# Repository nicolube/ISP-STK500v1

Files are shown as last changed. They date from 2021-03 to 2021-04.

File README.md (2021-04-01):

# ISP an Hand einer STK500v1
Diese ISP ist im grunde einer [STK500v1](http://ww1.microchip.com/downloads/en/Appnotes/doc2525.pdf) auch bekannt als [Arduino as ISP](https://www.arduino.cc/en/Tutorial/BuiltInExamples/ArduinoISP) mit der erweitern Schnittstelle für das [ATMega32 Board](/ATMega32%20Board/ATMega32%20Board.pdf) der IHK.
## Inhaltsverzeichnis
- [ISP an Hand einer STK500v1](#isp-an-hand-einer-stk500v1)
  - [Inhaltsverzeichnis](#inhaltsverzeichnis)
- [Bedienung](#bedienung)
  - [Jumper](#jumper)
  - [Arduino IDE](#arduino-ide)
  - [PlatformIO](#platformio)
  - [Schnittstellen Beschreibung](#schnittstellen-beschreibung)
- [Bauteile die vernachlässicht werden können](#bauteile-die-vernachlässicht-werden-können)
- [Programmieren der ISP](#programmieren-der-isp)
  - [Flashen der Firmware](#flashen-der-firmware)
- [Bestückungsplan](#bestückungsplan)
- [Schaltplan](#schaltplan)

# Bedienung

Das Board ist wie am Anfang genant eine STK500v1 und verhält sich auch so. Es registriert sich auf der Seite des PC als Serielle Schnittstelle.

Bevor Sie jedoch ihr zu Programirendes Board anschießen muss geprüft werden ob das zu programmirende Board eine eigene Spannungsversorgung hat und ob diese auf die AVR ISP Schnittstelle geführt wird. Sollte dies der Fall sein so entfernen Sie bitte JP2.

## Jumper

- ### JP1 Programmier Modus 
  
  JP1 muss im normalfall immer auf der Stellung (2,3) sein.
In der Stellung (1,2) ist die ISP im Selbst Programmiermodus und kann durch eine andere ISP geflasht werden. 

- ### JP2 Spannung über ISP

  Wenn die zu programmirende Board eine Stromaufnahme unter 100mA besitzt kann JP2 dazu genutzt werden die Board mit Spannung zu versorgen. **Dies darf nur im Spannungfreien zustand des Bords genutzt werden**

## Arduino IDE

Wählen Sie unter Tools den Port Ihrer STK500v1 und den Programmer *Arduino as ISP*.
Jetzt kann wie gewohnt ihr Programm hochgeladen werden.

Für genauere Informationen Klicken Sie [hier](https://www.arduino.cc/en/Tutorial/BuiltInExamples/ArduinoISP#program-the-bootloader) 

## PlatformIO

Bitte nutzen Sie für PlatformIO Projekt unser [Beispiel Projekt](/ISP/Beispiel).
Hier bei ist zu Beachten das in der [platform.ini](/ISP/Beispiel/platformio.ini) der *upload_port* angepasst werden muss.

## Schnittstellen Beschreibung

- SV1 und SV2 sind eine 6-, 10-Pin [AVR ISP Schittstelle](https://telecnatron.com/reference/pinouts/avr-isp/index.html).
- X1 ist ebenfalls eine ISP jedoch adoptiert auf den Parallelen Port des [ATMega32 Board](/ATMega32%20Board/ATMega32%20Board.pdf)
- X2 [USB Type B](https://static.giga.de/wp-content/uploads/2015/06/USB-2.0-A-B-Pins.png) zur Kommunikation mit dem PC.

# Bauteile die vernachlässicht werden können
Die Leiterplatte hat verschiedene Zusatzkomponenten die für die Funktion nicht zwingen benötigt werden, jedoch zusätzliche sicherheiten gewähren.

- Entstörkondensatoren USB (C8, C9)
- ESD-Schutz Diodennetzwerk (U1)
- FT232: Reset Pulldown (R5)
- FT232: 3,3V Entstörer (C7)

# Programmieren der ISP

Zum Programiren der ISP muss JP1 (1,2) und JP2 gesetzt werden.
Nun kann mittels einer anderen ISP die [Firmware](/ISP/Firmware/) geflasht werden.
Zudem muss SV1 oder SV2 auf ein Programmiergerät gebückt werden, dies kann z.b. eine USBASP oder eine andere ISP sein.

**Prüfen Sie die Stellung der Jumper!**

## Flashen der Firmware
1. Begeben Sie sich in den Verzeichnis des Projektes.
2. Prüfen Sie in der [platform.ini](/ISP/Firmware/platformio.ini) ob Sie den richtigen *upload_port* gewählt haben.
3. Öffenen Sie nun ein Terminal / CMD die [PlatformIO CLI](https://platformio.org/install/cli) installiert hat.
4. Setzen Sie die Fuses des Mikrocontrollers mit ```pio run --target fuses```.
5. Laden Sie nun die Firmware mit ```pio run --target upload``` hoch.

>  Bitte beachten Sie das der Jumper JP1 zur normalen nutzung wieder auf JP1 (2,3) gesetzt werden muss.

# Bestückungsplan
**Siehe [Stückliste](/ISP/Eagle/Stückliste.txt) für Bauteilinformation.**

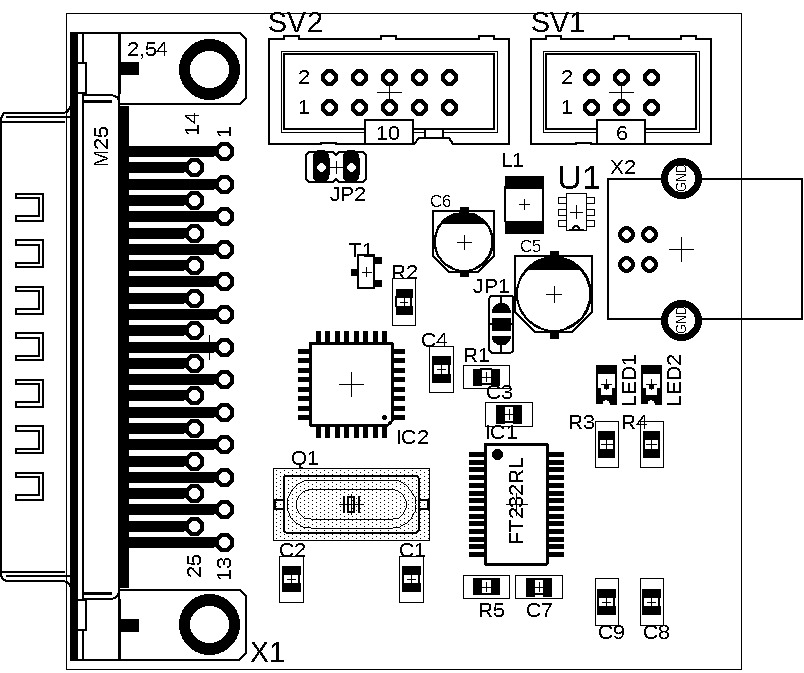
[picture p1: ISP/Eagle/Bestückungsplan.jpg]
Bestückungsplan


# Schaltplan
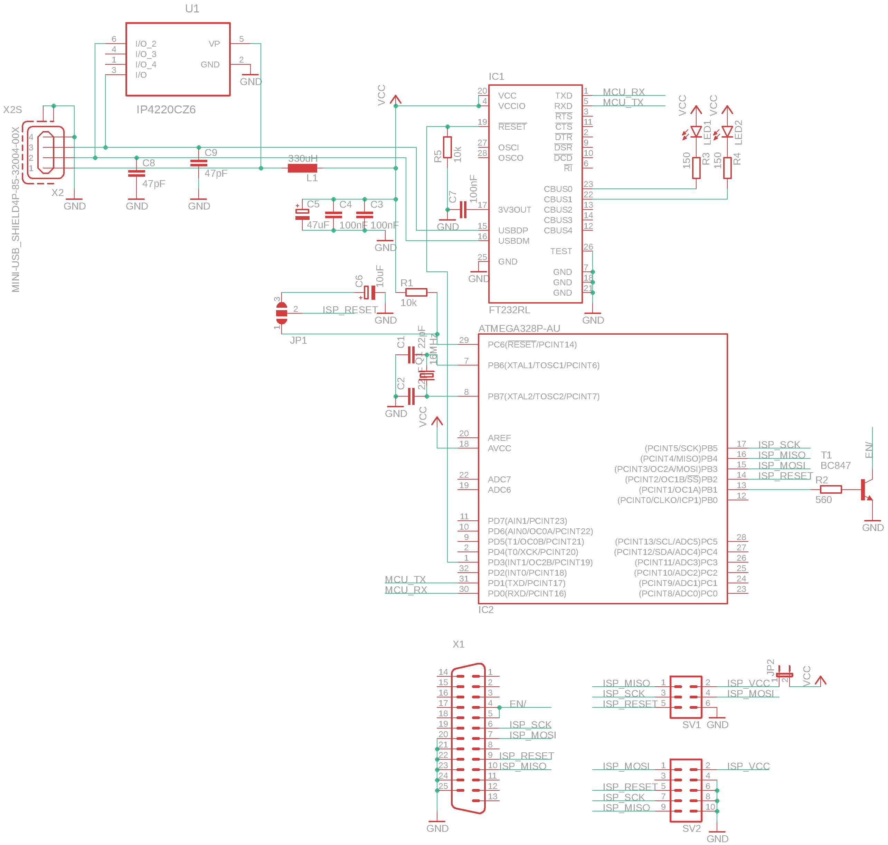
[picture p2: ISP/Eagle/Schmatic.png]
Schaltplan


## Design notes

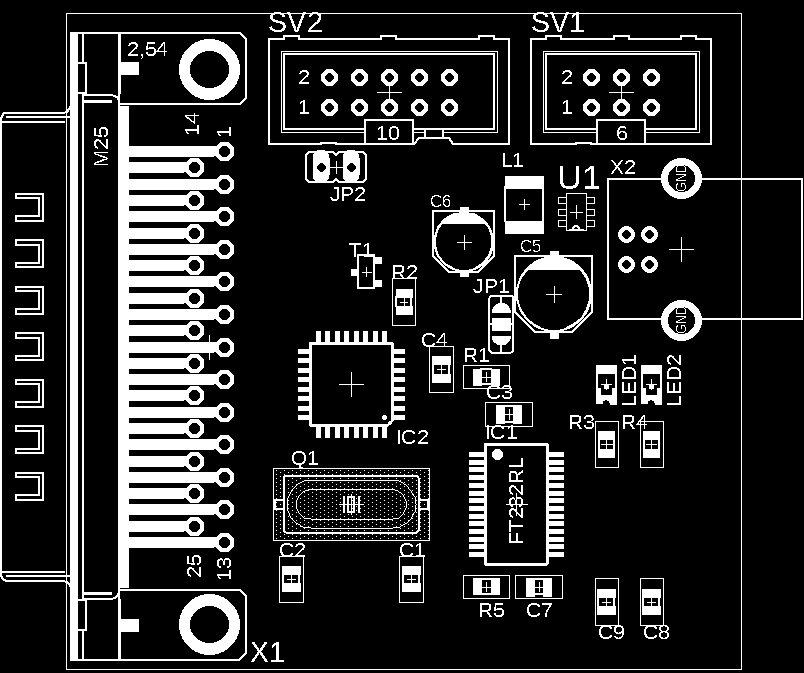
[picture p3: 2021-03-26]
ISP/Eagle/Bestückungsplan.png

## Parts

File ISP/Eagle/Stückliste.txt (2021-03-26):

Partlist

Exported from ISP.brd at 26.03.21 08:14

EAGLE Version 9.5.1 Copyright (c) 1988-2019 Autodesk, Inc.

Assembly variant: 

Part     Value                          Package          Library               Position (mil)        Orientation

C1       22pF                           C0805            resistor              (1150 300)            R90
C2       22pF                           C0805            resistor              (750 300)             R90
C3       100nF                          C0805            resistor              (1475 850)            R0
C4       100nF                          C0805            resistor              (1250 1000)           R90
C5       47uF                           PANASONIC_D      resistor              (1625 1250)           R270
C6       10uF                           PANASONIC_C      resistor              (1325 1425)           R270
C7       100nF                          C0805            resistor              (1575 275)            R180
C8       47pF                           C0805            resistor              (1950 225)            R270
C9       47pF                           C0805            resistor              (1800 225)            R270
IC1      FT232RL                        SSOP28           ftdichip              (1500 550)            R270
IC2      ATMEGA328P-AU                  QFP32_7X7_0.80   atmel                 (950 950)             R180
JP1                                     SJ_2             jumper                (1450 1150)           R90
JP2                                     JP1              jumper                (900 1675)            R90
L1       330uH                          L1812            resistor              (1525 1550)           R270
LED1                                    CHIPLED_1206     led                   (1800 950)            R180
LED2                                    CHIPLED_1206     led                   (1950 950)            R180
Q1       16MHz                          HC49UP           crystal               (950 550)             R0
R1       10k                            R0805            resistor              (1400 975)            R0
R2       560                            R0805            resistor              (1125 1225)           R90
R3       150                            R0805            resistor              (1800 750)            R270
R4       150                            R0805            resistor              (1950 750)            R270
R5       10k                            R0805            resistor              (1400 275)            R0
SV1                                     ML6              con-harting-ml        (1850 1925)           R0
SV2                                     ML10             con-ml                (1075 1925)           R0
T1       BC847                          SOT23            transistor            (1000 1325)           R90
U1       IP4220CZ6                      SOT95P275X110-6N IP4220CZ6             (1700 1525)           R180
X1                                      M25HP            con-subd              (475 1075)            R270
X2       MINI-USB_SHIELD4P-85-32004-00X 85-32004-00X     con-cypressindustries (2050 1400)           R180

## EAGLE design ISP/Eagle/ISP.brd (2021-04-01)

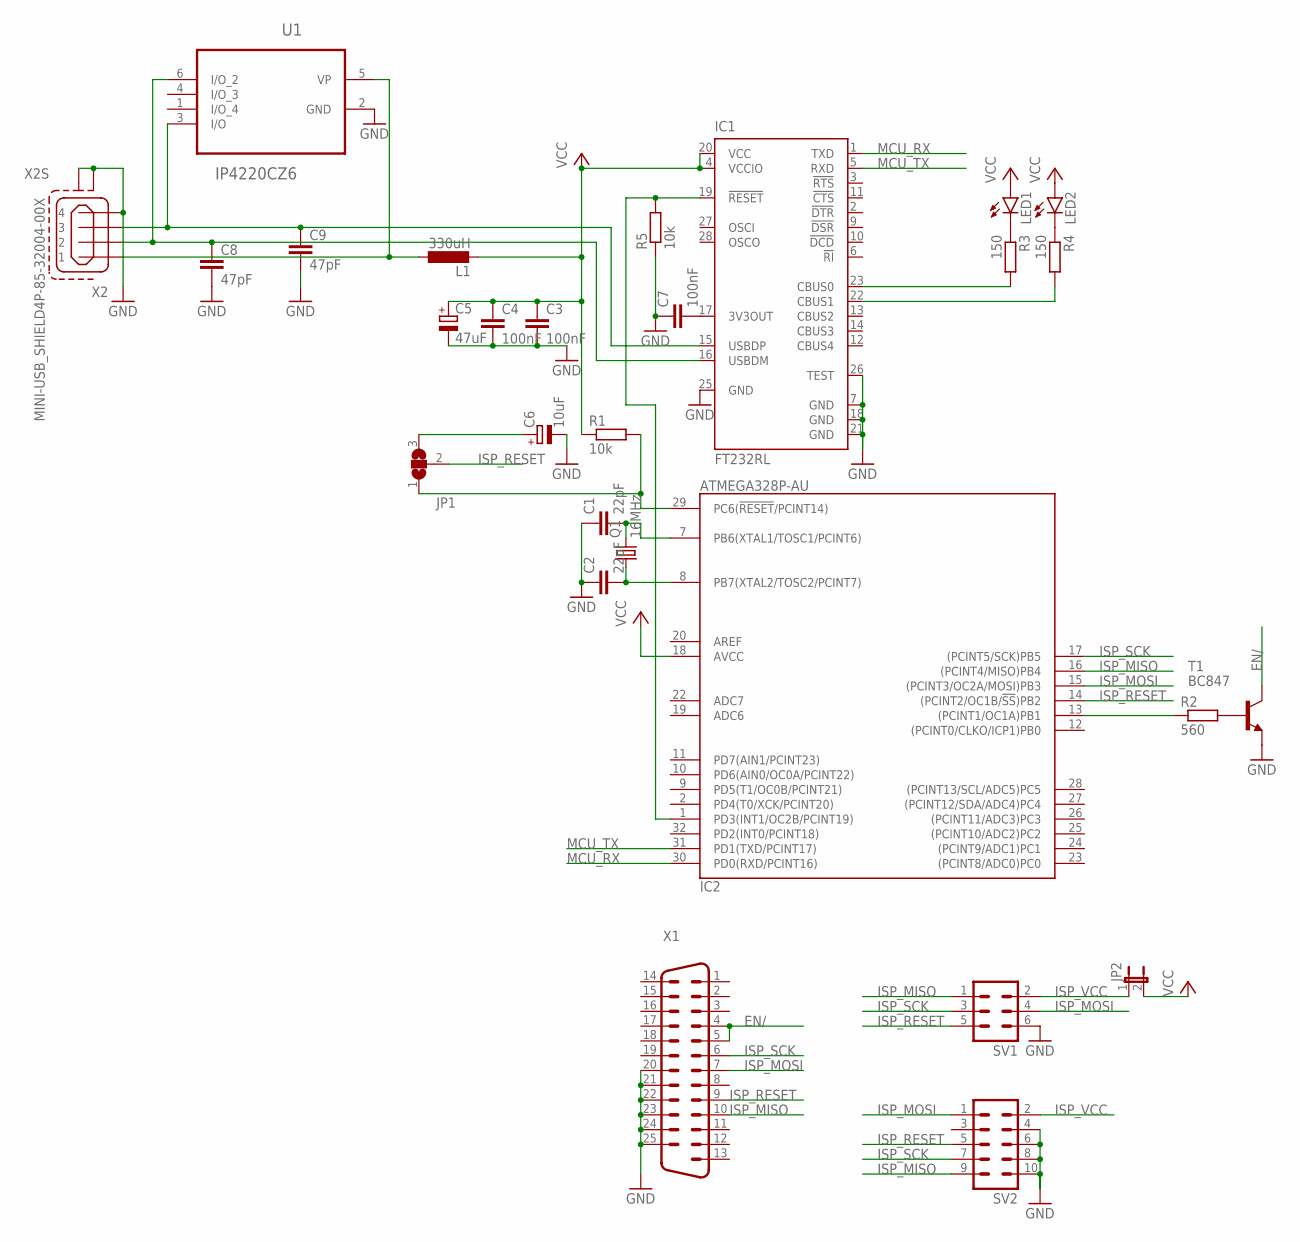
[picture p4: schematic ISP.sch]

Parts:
C1, C2: 22pF; C0805
C3, C4, C7: 100nF; C0805
C5: 47uF; PANASONIC_D
C6: 10uF; PANASONIC_C
C8, C9: 47pF; C0805
IC1: FT232RL; SSOP28
IC2: ATMEGA328P-AU; QFP32_7X7_0.80
JP1: SJ2W; SJ_2
JP2: JP1E; JP1
L1: 330uH; L1812
LED1, LED2: LEDCHIPLED_1206; CHIPLED_1206
Q1: 16MHz; HC49UP
R1, R5: 10k; R0805
R2: 560; R0805
R3, R4: 150; R0805
SV1: ML6
SV2: ML10
T1: BC847; SOT23
U1: IP4220CZ6; SOT95P275X110-6N
X1: M25HP
X2: MINI-USB_SHIELD4P-85-32004-00X; 85-32004-00X

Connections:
EN/: T1.3 (C), X1.4, X1.5
GND: C1.1, C2.1, C3.2, C4.2, C5.-, C6.-, C7.1, C8.2, C9.2, IC1.7 (GND), IC1.18 (GND), IC1.21 (GND), IC1.25 (GND), IC1.26 (TEST), IC2.3 (GND), IC2.5 (GND), IC2.21 (GND), R5.1, SV1.6, SV2.4, SV2.6, SV2.8, SV2.10, T1.2 (E), U1.2 (GND), X1.20, X1.21, X1.22, X1.23, X1.24, X1.25, X2.4, X2.M1 (S1), X2.M2 (S2)
ISP_MISO: IC2.16 ((PCINT4/MISO)PB4), SV1.1, SV2.9, X1.10
ISP_MOSI: IC2.15 ((PCINT3/OC2A/MOSI)PB3), SV1.4, SV2.1, X1.7
ISP_RESET: IC2.14 ((PCINT2/OC1B/!SS!)PB2), JP1.2, SV1.5, SV2.5, X1.9
ISP_SCK: IC2.17 ((PCINT5/SCK)PB5), SV1.3, SV2.7, X1.6
ISP_VCC: JP2.1, SV1.2, SV2.2
MCU_RX: IC1.1 (TXD), IC2.30 (PD0(RXD/PCINT16))
MCU_TX: IC1.5 (RXD), IC2.31 (PD1(TXD/PCINT17))
unnamed: IC2.29 (PC6(!RESET!/PCINT14)), JP1.1, R1.2
unnamed: C6.+, JP1.3
unnamed: C1.2, IC2.7 (PB6(XTAL1/TOSC1/PCINT6)), Q1.2
unnamed: C9.1, IC1.15 (USBDP), U1.3 (I/O), X2.3
unnamed: IC2.13 ((PCINT1/OC1A)PB1), R2.1
unnamed: R2.2, T1.1 (B)
unnamed: C8.1, IC1.16 (USBDM), U1.6 (I/O_2), X2.2
unnamed: C7.2, IC1.17 (3V3OUT)
unnamed: C2.2, IC2.8 (PB7(XTAL2/TOSC2/PCINT7)), Q1.1
unnamed: LED2.C, R4.1
unnamed: LED1.C, R3.1
unnamed: IC1.23 (CBUS0), R3.2
unnamed: IC1.22 (CBUS1), R4.2
unnamed: L1.1, U1.5 (VP), X2.1
unnamed: IC1.19 (!RESET), IC2.1 (PD3(INT1/OC2B/PCINT19)), R5.2
VCC: C3.1, C4.1, C5.+, IC1.4 (VCCIO), IC1.20 (VCC), IC2.4 (VCC), IC2.6 (VCC), IC2.18 (AVCC), JP2.2, L1.2, LED1.A, LED2.A, R1.1

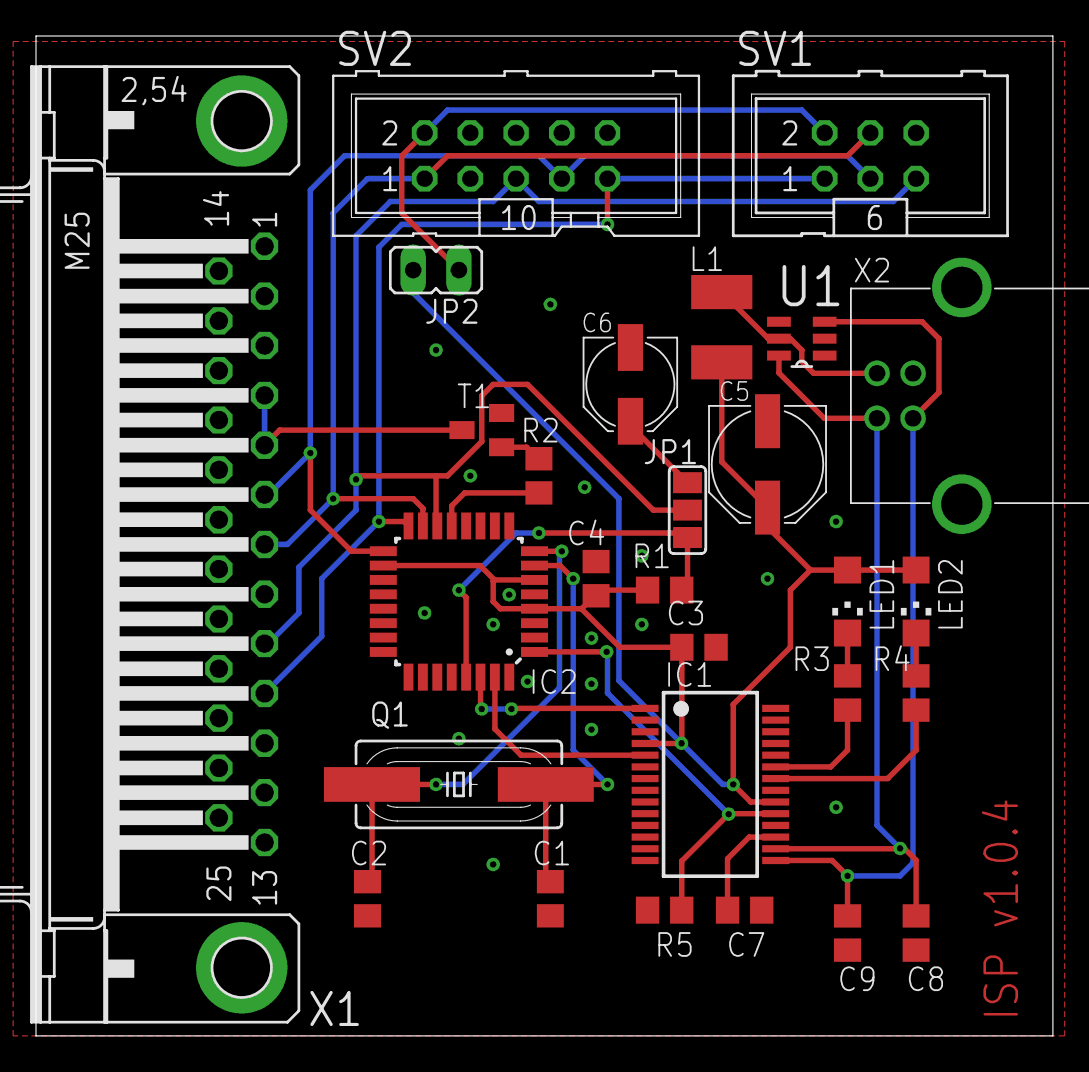
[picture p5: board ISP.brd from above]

Board: 2 copper layers, 56.5 x 55.5 mm, 28 parts (0 on the bottom side), 25 nets.

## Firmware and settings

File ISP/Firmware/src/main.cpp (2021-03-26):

#define PROG_EN 9
#define PROG_INV false
#define FT232_EN 3

unsigned long lSend = 0;

// ArduinoISP
// Copyright (c) 2008-2011 Randall Bohn
// If you require a license, see
// http://www.opensource.org/licenses/bsd-license.php
//
// This sketch turns the Arduino into a AVRISP using the following Arduino pins:
//
// Pin 10 is used to reset the target microcontroller.
//
// By default, the hardware SPI pins MISO, MOSI and SCK are used to communicate
// with the target. On all Arduinos, these pins can be found
// on the ICSP/SPI header:
//
//               MISO °. . 5V (!) Avoid this pin on Due, Zero...
//               SCK   . . MOSI
//                     . . GND
//
// On some Arduinos (Uno,...), pins MOSI, MISO and SCK are the same pins as
// digital pin 11, 12 and 13, respectively. That is why many tutorials instruct
// you to hook up the target to these pins. If you find this wiring more
// practical, have a define USE_OLD_STYLE_WIRING. This will work even when not
// using an Uno. (On an Uno this is not needed).
//
// Alternatively you can use any other digital pin by configuring
// software ('BitBanged') SPI and having appropriate defines for PIN_MOSI,
// PIN_MISO and PIN_SCK.
//
// IMPORTANT: When using an Arduino that is not 5V tolerant (Due, Zero, ...) as
// the programmer, make sure to not expose any of the programmer's pins to 5V.
// A simple way to accomplish this is to power the complete system (programmer
// and target) at 3V3.
//
// Put an LED (with resistor) on the following pins:
// 9: Heartbeat   - shows the programmer is running
// 8: Error       - Lights up if something goes wrong (use red if that makes sense)
// 7: Programming - In communication with the slave
//

#include "Arduino.h"
#undef SERIAL


#define PROG_FLICKER true

// Configure SPI clock (in Hz).
// E.g. for an ATtiny @ 128 kHz: the datasheet states that both the high and low
// SPI clock pulse must be > 2 CPU cycles, so take 3 cycles i.e. divide target
// f_cpu by 6:
//     #define SPI_CLOCK            (128000/6)
//
// A clock slow enough for an ATtiny85 @ 1 MHz, is a reasonable default:

#define SPI_CLOCK 		(1000000/6)


// Select hardware or software SPI, depending on SPI clock.
// Currently only for AVR, for other architectures (Due, Zero,...), hardware SPI
// is probably too fast anyway.

#if defined(ARDUINO_ARCH_AVR)

#if SPI_CLOCK > (F_CPU / 128)
#define USE_HARDWARE_SPI
#endif

#endif

// Configure which pins to use:

// The standard pin configuration.
#ifndef ARDUINO_HOODLOADER2

#define RESET     10 // Use pin 10 to reset the target rather than SS
#define LED_HB    6
#define LED_ERR   8
#define LED_PMODE 7

// Uncomment following line to use the old Uno style wiring
// (using pin 11, 12 and 13 instead of the SPI header) on Leonardo, Due...

// #define USE_OLD_STYLE_WIRING

#ifdef USE_OLD_STYLE_WIRING

#define PIN_MOSI	11
#define PIN_MISO	12
#define PIN_SCK		13

#endif

// HOODLOADER2 means running sketches on the ATmega16U2 serial converter chips
// on Uno or Mega boards. We must use pins that are broken out:
#else

#define RESET     	4
#define LED_HB    	7
#define LED_ERR   	6
#define LED_PMODE 	5

#endif

// By default, use hardware SPI pins:
#ifndef PIN_MOSI
#define PIN_MOSI 	MOSI
#endif

#ifndef PIN_MISO
#define PIN_MISO 	MISO
#endif

#ifndef PIN_SCK
#define PIN_SCK 	SCK
#endif

// Force bitbanged SPI if not using the hardware SPI pins:
#if (PIN_MISO != MISO) ||  (PIN_MOSI != MOSI) || (PIN_SCK != SCK)
#undef USE_HARDWARE_SPI
#endif


// Configure the serial port to use.
//
// Prefer the USB virtual serial port (aka. native USB port), if the Arduino has one:
//   - it does not autoreset (except for the magic baud rate of 1200).
//   - it is more reliable because of USB handshaking.
//
// Leonardo and similar have an USB virtual serial port: 'Serial'.
// Due and Zero have an USB virtual serial port: 'SerialUSB'.
//
// On the Due and Zero, 'Serial' can be used too, provided you disable autoreset.
// To use 'Serial': #define SERIAL Serial

#ifdef SERIAL_PORT_USBVIRTUAL
#define SERIAL SERIAL_PORT_USBVIRTUAL
#else
#define SERIAL Serial
#endif


// Configure the baud rate:

#define BAUDRATE	19200
// #define BAUDRATE	115200
// #define BAUDRATE	1000000


#define HWVER 2
#define SWMAJ 1
#define SWMIN 18

// STK Definitions
#define STK_OK      0x10
#define STK_FAILED  0x11
#define STK_UNKNOWN 0x12
#define STK_INSYNC  0x14
#define STK_NOSYNC  0x15
#define CRC_EOP     0x20 //ok it is a space...

void pulse(int pin, int times);

#ifdef USE_HARDWARE_SPI
#include "SPI.h"
#else

#define SPI_MODE0 0x00

class SPISettings {
  public:
    // clock is in Hz
    SPISettings(uint32_t clock, uint8_t bitOrder, uint8_t dataMode) : clock(clock) {
      (void) bitOrder;
      (void) dataMode;
    };

  private:
    uint32_t clock;

    friend class BitBangedSPI;
};

class BitBangedSPI {
  public:
    void begin() {
      digitalWrite(PIN_SCK, LOW);
      digitalWrite(PIN_MOSI, LOW);
      pinMode(PIN_SCK, OUTPUT);
      pinMode(PIN_MOSI, OUTPUT);
      pinMode(PIN_MISO, INPUT);
    }

    void beginTransaction(SPISettings settings) {
      pulseWidth = (500000 + settings.clock - 1) / settings.clock;
      if (pulseWidth == 0)
        pulseWidth = 1;
    }

    void end() {}

    uint8_t transfer (uint8_t b) {
      for (unsigned int i = 0; i < 8; ++i) {
        digitalWrite(PIN_MOSI, (b & 0x80) ? HIGH : LOW);
        digitalWrite(PIN_SCK, HIGH);
        delayMicroseconds(pulseWidth);
        b = (b << 1) | digitalRead(PIN_MISO);
        digitalWrite(PIN_SCK, LOW); // slow pulse
        delayMicroseconds(pulseWidth);
      }
      return b;
    }

  private:
    unsigned long pulseWidth; // in microseconds
};

static BitBangedSPI SPI;

#endif



int error = 0;
int pmode = 0;
// address for reading and writing, set by 'U' command
unsigned int here;
uint8_t buff[256]; // global block storage

#define beget16(addr) (*addr * 256 + *(addr+1) )
typedef struct param {
  uint8_t devicecode;
  uint8_t revision;
  uint8_t progtype;
  uint8_t parmode;
  uint8_t polling;
  uint8_t selftimed;
  uint8_t lockbytes;
  uint8_t fusebytes;
  uint8_t flashpoll;
  uint16_t eeprompoll;
  uint16_t pagesize;
  uint16_t eepromsize;
  uint32_t flashsize;
}
parameter;

parameter param;

// this provides a heartbeat on pin 9, so you can tell the software is running.
uint8_t hbval = 128;
int8_t hbdelta = 8;
void heartbeat() {
  static unsigned long last_time = 0;
  unsigned long now = millis();
  if ((now - last_time) < 40)
    return;
  last_time = now;
  if (hbval > 192) hbdelta = -hbdelta;
  if (hbval < 32) hbdelta = -hbdelta;
  hbval += hbdelta;
  analogWrite(LED_HB, hbval);
}

static bool rst_active_high;

void reset_target(bool reset) {
  digitalWrite(RESET, ((reset && rst_active_high) || (!reset && !rst_active_high)) ? HIGH : LOW);
}

uint8_t getch() {
  while (!SERIAL.available()) {
    if (millis() > lSend)
      digitalWrite(PROG_EN, PROG_INV);
  }
  lSend = millis() + 100;
  return SERIAL.read();
}
void fill(int n) {
  for (int x = 0; x < n; x++) {
    buff[x] = getch();
  }
}

#define PTIME 30
void pulse(int pin, int times) {
  do {
    digitalWrite(pin, HIGH);
    delay(PTIME);
    digitalWrite(pin, LOW);
    delay(PTIME);
  } while (times--);
}

void prog_lamp(int state) {
  if (PROG_FLICKER) {
    digitalWrite(LED_PMODE, state);
  }
}

uint8_t spi_transaction(uint8_t a, uint8_t b, uint8_t c, uint8_t d) {
  SPI.transfer(a);
  SPI.transfer(b);
  SPI.transfer(c);
  return SPI.transfer(d);
}

void empty_reply() {
  if (CRC_EOP == getch()) {
    SERIAL.print((char)STK_INSYNC);
    SERIAL.print((char)STK_OK);
  } else {
    error++;
    SERIAL.print((char)STK_NOSYNC);
  }
}

void breply(uint8_t b) {
  if (CRC_EOP == getch()) {
    SERIAL.print((char)STK_INSYNC);
    SERIAL.print((char)b);
    SERIAL.print((char)STK_OK);
  } else {
    error++;
    SERIAL.print((char)STK_NOSYNC);
  }
}

void get_version(uint8_t c) {
  switch (c) {
    case 0x80:
      breply(HWVER);
      break;
    case 0x81:
      breply(SWMAJ);
      break;
    case 0x82:
      breply(SWMIN);
      break;
    case 0x93:
      breply('S'); // serial programmer
      break;
    default:
      breply(0);
  }
}

void set_parameters() {
  // call this after reading parameter packet into buff[]
  param.devicecode = buff[0];
  param.revision   = buff[1];
  param.progtype   = buff[2];
  param.parmode    = buff[3];
  param.polling    = buff[4];
  param.selftimed  = buff[5];
  param.lockbytes  = buff[6];
  param.fusebytes  = buff[7];
  param.flashpoll  = buff[8];
  // ignore buff[9] (= buff[8])
  // following are 16 bits (big endian)
  param.eeprompoll = beget16(&buff[10]);
  param.pagesize   = beget16(&buff[12]);
  param.eepromsize = beget16(&buff[14]);

  // 32 bits flashsize (big endian)
  param.flashsize = buff[16] * 0x01000000
                    + buff[17] * 0x00010000
                    + buff[18] * 0x00000100
                    + buff[19];

  // AVR devices have active low reset, AT89Sx are active high
  rst_active_high = (param.devicecode >= 0xe0);
}

void start_pmode() {
  // Reset target before driving PIN_SCK or PIN_MOSI

  // SPI.begin() will configure SS as output, so SPI master mode is selected.
  // We have defined RESET as pin 10, which for many Arduinos is not the SS pin.
  // So we have to configure RESET as output here,
  // (reset_target() first sets the correct level)
  reset_target(true);
  pinMode(RESET, OUTPUT);
  SPI.begin();
  SPI.beginTransaction(SPISettings(SPI_CLOCK, MSBFIRST, SPI_MODE0));

  // See AVR datasheets, chapter "SERIAL_PRG Programming Algorithm":

  // Pulse RESET after PIN_SCK is low:
  digitalWrite(PIN_SCK, LOW);
  delay(20); // discharge PIN_SCK, value arbitrarily chosen
  reset_target(false);
  // Pulse must be minimum 2 target CPU clock cycles so 100 usec is ok for CPU
  // speeds above 20 KHz
  delayMicroseconds(100);
  reset_target(true);

  // Send the enable programming command:
  delay(50); // datasheet: must be > 20 msec
  spi_transaction(0xAC, 0x53, 0x00, 0x00);
  pmode = 1;
}

void end_pmode() {
  SPI.end();
  // We're about to take the target out of reset so configure SPI pins as input
  pinMode(PIN_MOSI, INPUT);
  pinMode(PIN_SCK, INPUT);
  reset_target(false);
  pinMode(RESET, INPUT);
  pmode = 0;
}

void universal() {
  uint8_t ch;

  fill(4);
  ch = spi_transaction(buff[0], buff[1], buff[2], buff[3]);
  breply(ch);
}

void flash(uint8_t hilo, unsigned int addr, uint8_t data) {
  spi_transaction(0x40 + 8 * hilo,
                  addr >> 8 & 0xFF,
                  addr & 0xFF,
                  data);
}
void commit(unsigned int addr) {
  if (PROG_FLICKER) {
    prog_lamp(LOW);
  }
  spi_transaction(0x4C, (addr >> 8) & 0xFF, addr & 0xFF, 0);
  if (PROG_FLICKER) {
    delay(PTIME);
    prog_lamp(HIGH);
  }
}

unsigned int current_page() {
  if (param.pagesize == 32) {
    return here & 0xFFFFFFF0;
  }
  if (param.pagesize == 64) {
    return here & 0xFFFFFFE0;
  }
  if (param.pagesize == 128) {
    return here & 0xFFFFFFC0;
  }
  if (param.pagesize == 256) {
    return here & 0xFFFFFF80;
  }
  return here;
}

// write (length) bytes, (start) is a byte address
uint8_t write_eeprom_chunk(unsigned int start, unsigned int length) {
  // this writes byte-by-byte, page writing may be faster (4 bytes at a time)
  fill(length);
  prog_lamp(LOW);
  for (unsigned int x = 0; x < length; x++) {
    unsigned int addr = start + x;
    spi_transaction(0xC0, (addr >> 8) & 0xFF, addr & 0xFF, buff[x]);
    delay(45);
  }
  prog_lamp(HIGH);
  return STK_OK;
}


#define EECHUNK (32)
uint8_t write_eeprom(unsigned int length) {
  // here is a word address, get the byte address
  unsigned int start = here * 2;
  unsigned int remaining = length;
  if (length > param.eepromsize) {
    error++;
    return STK_FAILED;
  }
  while (remaining > EECHUNK) {
    write_eeprom_chunk(start, EECHUNK);
    start += EECHUNK;
    remaining -= EECHUNK;
  }
  write_eeprom_chunk(start, remaining);
  return STK_OK;
}

uint8_t write_flash_pages(int length) {
  int x = 0;
  unsigned int page = current_page();
  while (x < length) {
    if (page != current_page()) {
      commit(page);
      page = current_page();
    }
    flash(LOW, here, buff[x++]);
    flash(HIGH, here, buff[x++]);
    here++;
  }

  commit(page);

  return STK_OK;
}

void write_flash(int length) {
  fill(length);
  if (CRC_EOP == getch()) {
    SERIAL.print((char) STK_INSYNC);
    SERIAL.print((char) write_flash_pages(length));
  } else {
    error++;
    SERIAL.print((char) STK_NOSYNC);
  }
}

void program_page() {
  char result = (char) STK_FAILED;
  unsigned int length = 256 * getch();
  length += getch();
  char memtype = getch();
  // flash memory @here, (length) bytes
  if (memtype == 'F') {
    write_flash(length);
    return;
  }
  if (memtype == 'E') {
    result = (char)write_eeprom(length);
    if (CRC_EOP == getch()) {
      SERIAL.print((char) STK_INSYNC);
      SERIAL.print(result);
    } else {
      error++;
      SERIAL.print((char) STK_NOSYNC);
    }
    return;
  }
  SERIAL.print((char)STK_FAILED);
  return;
}

uint8_t flash_read(uint8_t hilo, unsigned int addr) {
  return spi_transaction(0x20 + hilo * 8,
                         (addr >> 8) & 0xFF,
                         addr & 0xFF,
                         0);
}

char flash_read_page(int length) {
  for (int x = 0; x < length; x += 2) {
    uint8_t low = flash_read(LOW, here);
    SERIAL.print((char) low);
    uint8_t high = flash_read(HIGH, here);
    SERIAL.print((char) high);
    here++;
  }
  return STK_OK;
}

char eeprom_read_page(int length) {
  // here again we have a word address
  int start = here * 2;
  for (int x = 0; x < length; x++) {
    int addr = start + x;
    uint8_t ee = spi_transaction(0xA0, (addr >> 8) & 0xFF, addr & 0xFF, 0xFF);
    SERIAL.print((char) ee);
  }
  return STK_OK;
}

void read_page() {
  char result = (char)STK_FAILED;
  int length = 256 * getch();
  length += getch();
  char memtype = getch();
  if (CRC_EOP != getch()) {
    error++;
    SERIAL.print((char) STK_NOSYNC);
    return;
  }
  SERIAL.print((char) STK_INSYNC);
  if (memtype == 'F') result = flash_read_page(length);
  if (memtype == 'E') result = eeprom_read_page(length);
  SERIAL.print(result);
}

void read_signature() {
  if (CRC_EOP != getch()) {
    error++;
    SERIAL.print((char) STK_NOSYNC);
    return;
  }
  SERIAL.print((char) STK_INSYNC);
  uint8_t high = spi_transaction(0x30, 0x00, 0x00, 0x00);
  SERIAL.print((char) high);
  uint8_t middle = spi_transaction(0x30, 0x00, 0x01, 0x00);
  SERIAL.print((char) middle);
  uint8_t low = spi_transaction(0x30, 0x00, 0x02, 0x00);
  SERIAL.print((char) low);
  SERIAL.print((char) STK_OK);
}
//////////////////////////////////////////
//////////////////////////////////////////


////////////////////////////////////
////////////////////////////////////
void avrisp() {
  uint8_t ch = getch();
  digitalWrite(PROG_EN, !PROG_INV);
  switch (ch) {
    case '0': // signon
      error = 0;
      empty_reply();
      break;
    case '1':
      if (getch() == CRC_EOP) {
        SERIAL.print((char) STK_INSYNC);
        SERIAL.print("AVR ISP");
        SERIAL.print((char) STK_OK);
      }
      else {
        error++;
        SERIAL.print((char) STK_NOSYNC);
      }
      break;
    case 'A':
      get_version(getch());
      break;
    case 'B':
      fill(20);
      set_parameters();
      empty_reply();
      break;
    case 'E': // extended parameters - ignore for now
      fill(5);
      empty_reply();
      break;
    case 'P':
      if (!pmode)
        start_pmode();
      empty_reply();
      break;
    case 'U': // set address (word)
      here = getch();
      here += 256 * getch();
      empty_reply();
      break;

    case 0x60: //STK_PROG_FLASH
      getch(); // low addr
      getch(); // high addr
      empty_reply();
      break;
    case 0x61: //STK_PROG_DATA
      getch(); // data
      empty_reply();
      break;

    case 0x64: //STK_PROG_PAGE
      program_page();
      break;

    case 0x74: //STK_READ_PAGE 't'
      read_page();
      break;

    case 'V': //0x56
      universal();
      break;
    case 'Q': //0x51
      error = 0;
      end_pmode();
      empty_reply();
      break;

    case 0x75: //STK_READ_SIGN 'u'
      read_signature();
      break;

    // expecting a command, not CRC_EOP
    // this is how we can get back in sync
    case CRC_EOP:
      error++;
      SERIAL.print((char) STK_NOSYNC);
      break;

    // anything else we will return STK_UNKNOWN
    default:
      error++;
      if (CRC_EOP == getch())
        SERIAL.print((char)STK_UNKNOWN);
      else
        SERIAL.print((char)STK_NOSYNC);
  }
}

void setup() {
  SERIAL.begin(BAUDRATE);
  pinMode(FT232_EN, OUTPUT);
  digitalWrite(FT232_EN, false);

  pinMode(PROG_EN, OUTPUT);
  digitalWrite(PROG_EN, PROG_INV);

  pinMode(LED_PMODE, OUTPUT);
  pulse(LED_PMODE, 2);
  pinMode(LED_ERR, OUTPUT);
  pulse(LED_ERR, 2);
  pinMode(LED_HB, OUTPUT);
  pulse(LED_HB, 2);
  digitalWrite(FT232_EN, true);

}

void loop(void) {
  // is pmode active?
  if (pmode) {
    digitalWrite(LED_PMODE, HIGH);
  } else {
    digitalWrite(LED_PMODE, LOW);
  }
  // is there an error?
  if (error) {
    digitalWrite(LED_ERR, HIGH);
  } else {
    digitalWrite(LED_ERR, LOW);
  }

    if (millis() > lSend)
      digitalWrite(PROG_EN, PROG_INV);
  // light the heartbeat LED
  heartbeat();
  if (SERIAL.available()) {
    avrisp();
  }
}

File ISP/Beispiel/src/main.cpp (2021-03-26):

#include <Arduino.h>
#include <LiquidCrystal.h>

LiquidCrystal lcd(PB0, PB1, PB2, PB4, PB5, PB6, PB7);



void setup() {
  Serial.begin(9600);
  Serial.println("Init");
  lcd.begin(16,2);
  lcd.backlight();
  lcd.home();
  lcd.print("AP Winter 2021");
  lcd.setCursor(0,1);
  lcd.print("Demo");
  delay(2000);
  lcd.clear();
}

void loop() {

  lcd.home();
  lcd.print("PA0: ");
  lcd.print(analogRead(PA0)*0.004882813);
  lcd.print("V   ");
  lcd.setCursor(0,1);
  lcd.print("PA1: ");
  lcd.print(analogRead(PA1)*0.004882813);
  lcd.print("V   ");

}
